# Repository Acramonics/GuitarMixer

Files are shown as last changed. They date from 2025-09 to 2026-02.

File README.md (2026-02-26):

AEGM: Acoustic/Electric Guitar Mixer
====================================

**Andrew Martin (c) 2025 - 2026**

**Still not working properly yet**

**V1.3 has switched to a dual rail power supply to save the effort of
  biasing all the op amp inputs. Awaiting the new boards**

*AEGM* is designed as a simple 2-channel mixer for guitars like the
PRS range that have both acoustic (piezo) and coil pickups. The
guitars have a combined output, but it doesn't work that well since
the piezo output needs a higher impedance than a standard guitar amp
to work well and your options for balancing the volumes are limited.
Also, you cannot use a pedal on the coil output without also putting
it on the piezo output.

The guitar gives you the option of using two separate outputs which is
fine if you have two amps, but this little mixer is designed to allow
you to use the two outputs separately and then send them to a single
amp.

**V1.2 was simulated in KiCad-Spice and appeared to be working
  properly, but when built was overlayed with noise and distorted.**

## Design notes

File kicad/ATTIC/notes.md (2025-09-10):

Things to try to make this work
===============================

1. Try using DC coupling on the 'scope

2. Try a larger PSU voltage

3. Try more PSU smoothing

4. Try the mixer stage alone on music

5. Try the buffer stage alone on music

Filtering
---------

4. Do we have just an HF effect or also ringing (impedance problems)?

5. Add 1K/10nF R-C low pass filter - before or after the opamp

6. Add 22pF cap U2 Pin3 to ground for high frequencies

Decoupling
----------

7. Add 470nF or 1uF cap between R5/R7 and U2 Pin2

8. Or add 100nF before R5 and R7

9. Try 100R and 10uF (+ to output) after opamp

Gain / feedback
---------------

10. Try R11 at 10k or 1k or shorted to reduce gain of inverter

11. Try R10 at 10K or 1k to reduce gain

12. Try R10 at 220k to increase gain

13. Add 4.7pF cap in parallel with R10

Bias
----

14. Remove R9 (9v positive bias)

15. Remove R8 (no positive bias)

16. Remove R8 and short R9 (non-inv input straight to earth)

17. Try R8 and R9 at 10K to increase current

18. Try C8 = 1uF or 47uF

19. Try C8 = 2.2uF and C7 = 22uF

Impedance matching
------------------

20. Try R5/R7 at 1K to reduce output impedance (and noise) from buffers

Major changes
-------------

21. Try separating signal ground from -ve power

22. Try a non-inverting amplifier for the mixer part (see below)

--------------------------------------------------------------------

Square wave testing
-------------------

https://sound-au.com/articles/squarewave.htm

High-frequency boost leads to peak at the start

1K + 10nF low pass filter (~16kHz) might help

Might prefer to use a higher-order 24dB/octave filter tuned to (say)
22kHz.

A descending flat top of a square wave indicates bass attentuation
An ascending flat top of a square wave indicates bass boost

Non-inverting amp
-----------------
https://share.google/images/nToTiObG5TNGJYSms
https://www.allaboutcircuits.com/video-tutorials/basic-amplifier-configurations-non-inverting-amplifier/

```
           | \
Vin -------|+ \
           |   \___________ Vout
           |   /        |
       ----|- /         |
       |   | /          |
       |                |
       +------|R2|------|
       |
       |
      ---
       R1
      ---
       |
       |
      GND

Vout = Gcl (closed-loop gain) = 1 + (R2/R1)
```

Other web pages:
----------------
https://www.reddit.com/r/diypedals/s/R89ESHo1lh
Transistor based mixer: http://www.seekic.com/circuit_diagram/Audio_Circuit/Mixer/
Other mixer circuits: http://www.seekic.com/circuit_diagram/Audio_Circuit/Mixer/
JFET mixer: https://www.diy-electronic-projects.com/p30-FET-Audio-Mixer
Inverting OpAmp mixer: https://es.pinterest.com/pin/714031715956747662/
Hybrid mixer: https://www.electroniq.net/audio/hybrid-2-channel-audio-mixer-circuit.html#google_vignette
Dual rail mixer: https://modwiggler.com/forum/viewtopic.php?t=258014
GGG Mixer: https://generalguitargadgets.com/pdf/ggg_mixer_sc.pdf
Vero Mixer: https://tagboardeffects.blogspot.com/2013/01/2-channel-mixer.html

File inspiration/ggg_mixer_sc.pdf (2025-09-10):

# Mini Mixer

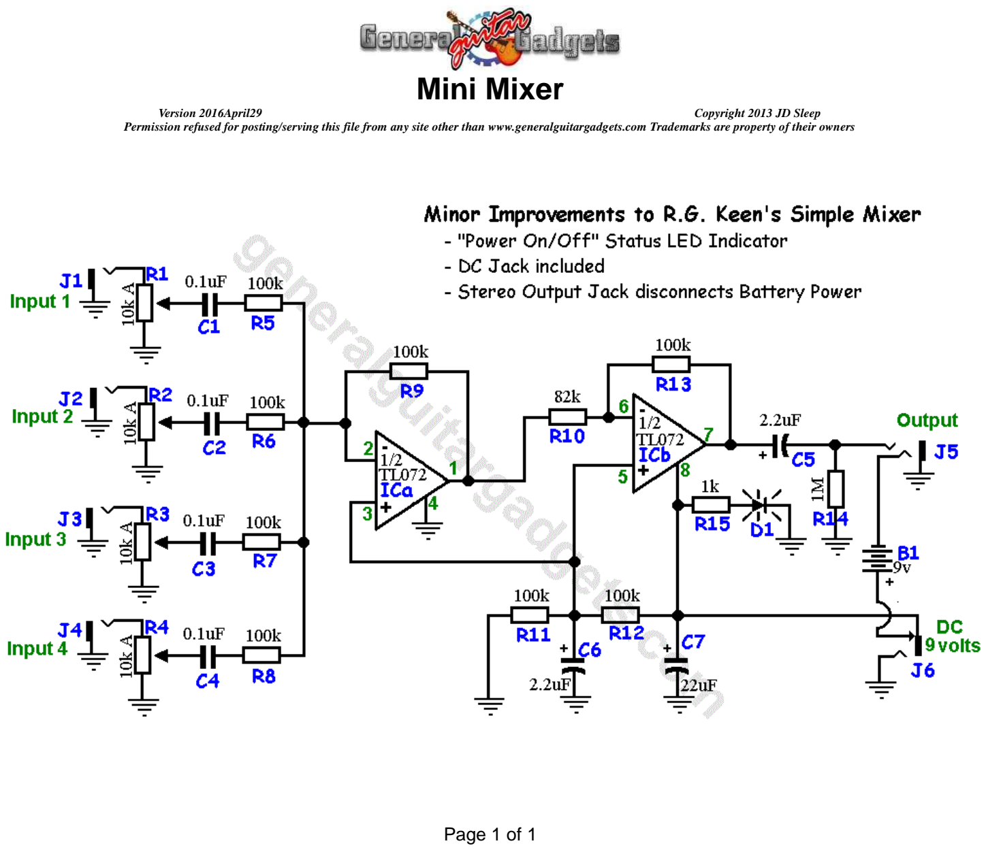
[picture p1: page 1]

Version 2016April29 | Copyright 2013 JD Sleep
Permission refused for posting/serving this file from any site other than www.generalguitargadgets.com Trademarks are property of their owners

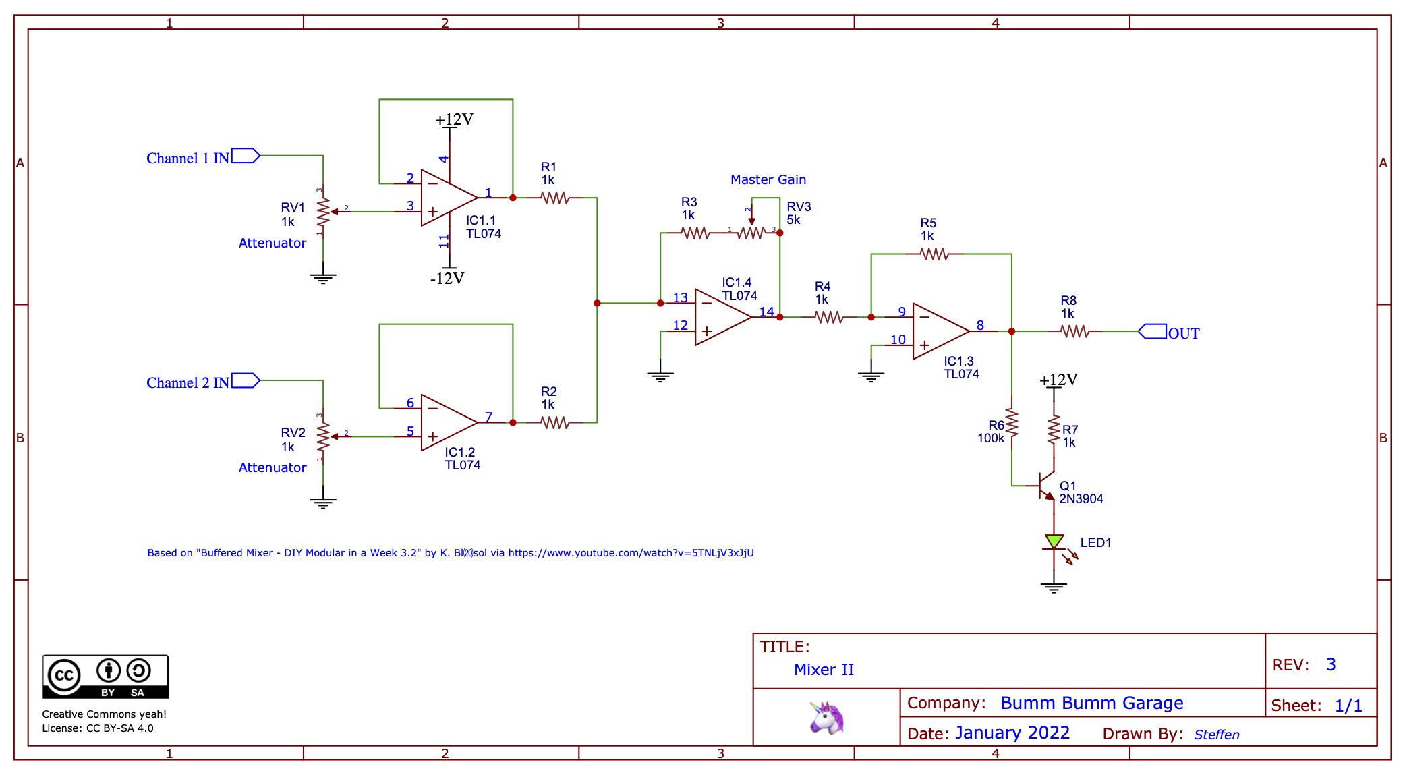
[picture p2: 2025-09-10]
inspiration/Bumm-Bumm-Garage-Mixer-II-Rev3-Schematic.png

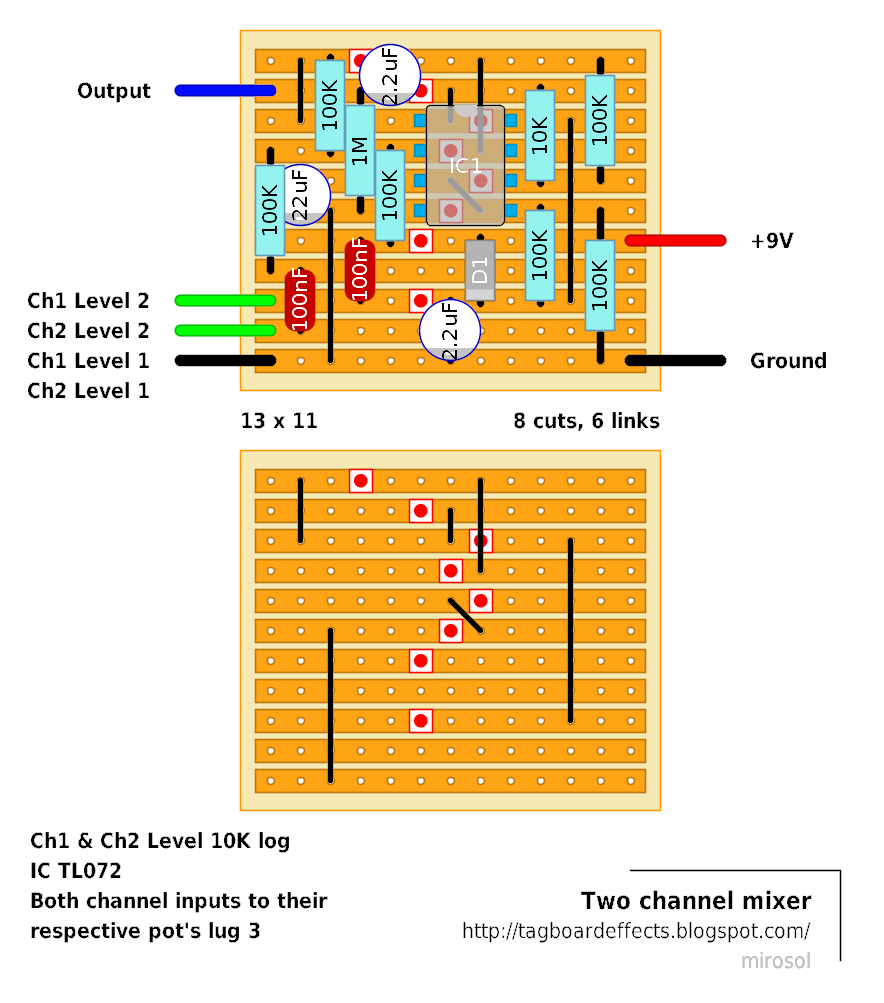
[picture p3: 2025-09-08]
inspiration/2chan-mixer-rev1-light.png

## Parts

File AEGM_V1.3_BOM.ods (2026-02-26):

Reference | Qty | Value | Footprint
C1,C2 | 2 | 10pF | Capacitor_THT:C_Disc_D4.3mm_W1.9mm_P5.00mm
C3 | 1 | 2.2uF | Capacitor_THT:CP_Radial_D5.0mm_P2.00mm
C4,C8,C9 | 3 | 100nF | Capacitor_THT:C_Rect_L7.0mm_W3.5mm_P5.00mm
C5,C6 | 2 | 22uF | Capacitor_THT:CP_Radial_D5.0mm_P2.00mm
C7 | 1 | 10uF | Capacitor_THT:CP_Radial_D5.0mm_P2.00mm
C101 | 1 | 1pF | Capacitor_THT:C_Disc_D4.3mm_W1.9mm_P5.00mm
C102 | 1 | 4.7nF | Capacitor_THT:C_Rect_L7.2mm_W2.5mm_P5.00mm_FKS2_FKP2_MKS2_MKP2
C103 | 1 | 330nF | Capacitor_THT:C_Rect_L7.2mm_W2.5mm_P5.00mm_FKS2_FKP2_MKS2_MKP2
C105,C205 | 2 | 1uF | Capacitor_THT:C_Rect_L7.2mm_W4.5mm_P5.00mm_FKS2_FKP2_MKS2_MKP2
C203 | 1 | 100nF | Capacitor_THT:C_Rect_L7.2mm_W2.5mm_P5.00mm_FKS2_FKP2_MKS2_MKP2
D1 | 1 | 1N5817 | Diode_THT:D_DO-35_SOD27_P7.62mm_Horizontal
J1,J2,J3,J6 | 4 | Conn_01x03_Pin | Connector_Molex:Molex_KK-254_AE-6410-03A_1x03_P2.54mm_Vertical
J4,J5 | 2 | Conn_01x02_Pin | Connector_Molex:Molex_KK-254_AE-6410-02A_1x02_P2.54mm_Vertical
Q1 | 1 | 2N5457 | Package_TO_SOT_THT:TO-92_HandSolder
R1,R2,R3,R103 | 4 | 10K | Resistor_THT:R_Axial_DIN0207_L6.3mm_D2.5mm_P10.16mm_Horizontal
R4,R201 | 2 | 1M | Resistor_THT:R_Axial_DIN0207_L6.3mm_D2.5mm_P10.16mm_Horizontal
R5 | 1 | 680R | Resistor_THT:R_Axial_DIN0207_L6.3mm_D2.5mm_P2.54mm_Vertical
R6 | 1 | 220R | Resistor_THT:R_Axial_DIN0207_L6.3mm_D2.5mm_P2.54mm_Vertical
R102 | 1 | 220K | Resistor_THT:R_Axial_DIN0207_L6.3mm_D2.5mm_P10.16mm_Horizontal
R108,R208 | 2 | 4K7 | Resistor_THT:R_Axial_DIN0207_L6.3mm_D2.5mm_P2.54mm_Vertical
R1011,R1012 | 2 | 4M7 | Resistor_THT:R_Axial_DIN0207_L6.3mm_D2.5mm_P10.16mm_Horizontal
RV1 | 1 | 100KB | 100K Linear Pot
RV101,RV201 | 2 | A100K | 100K Audio (Log) Pot
SW1 | 1 | SW_SPST | ACRM:SPDT_SlideSwitch
U1,U2 | 2 | TL072 | Package_DIP:DIP-8_W7.62mm
U3 | 1 | LM317L | Package_TO_SOT_THT:TO-92_HandSolder
U4 | 1 | LMC7660 | Package_DIP:DIP-8_W7.62mm

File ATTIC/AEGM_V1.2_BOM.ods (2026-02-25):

Reference | Qty | Value | Footprint
C1,C2 | 2 | 10pF | Capacitor_THT:C_Disc_D4.3mm_W1.9mm_P5.00mm
C3 | 1 | 2.2uF | Capacitor_THT:CP_Radial_D5.0mm_P2.00mm
C4 | 1 | 4.7uF | Capacitor_THT:CP_Radial_D5.0mm_P2.00mm
C5 | 1 | 22uF | Capacitor_THT:CP_Radial_D5.0mm_P2.00mm
C101 | 1 | 1pF | Capacitor_THT:C_Disc_D4.3mm_W1.9mm_P5.00mm
C102 | 1 | 4.7nF | Capacitor_THT:C_Rect_L7.2mm_W2.5mm_P5.00mm_FKS2_FKP2_MKS2_MKP2
C103,C104,C203,C204 | 4 | 100nF | Capacitor_THT:C_Rect_L7.2mm_W2.5mm_P5.00mm_FKS2_FKP2_MKS2_MKP2
C105,C205 | 2 | 1uF | Capacitor_THT:C_Rect_L7.2mm_W4.5mm_P5.00mm_FKS2_FKP2_MKS2_MKP2
C202 | 1 | 1nF | Capacitor_THT:C_Rect_L7.2mm_W2.5mm_P5.00mm_FKS2_FKP2_MKS2_MKP2
D1 | 1 | 1N5817 | Diode_THT:D_DO-41_SOD81_P10.16mm_Horizontal
J1,J2,J3,J6 | 4 | Conn_01x03_Pin | Connector_Molex:Molex_KK-254_AE-6410-03A_1x03_P2.54mm_Vertical
J4,J5 | 2 | Conn_01x02_Pin | Connector_Molex:Molex_KK-254_AE-6410-02A_1x02_P2.54mm_Vertical
Q1 | 1 | 2N5457 | Package_TO_SOT_THT:TO-92_HandSolder
R1,R2,R3,R103,R108,R208 | 6 | 10K | Resistor_THT:R_Axial_DIN0207_L6.3mm_D2.5mm_P10.16mm_Horizontal
R4,R201 | 2 | 1M | Resistor_THT:R_Axial_DIN0207_L6.3mm_D2.5mm_P10.16mm_Horizontal
R5,R6,R104,R105,R204,R205 | 6 | 100K | Resistor_THT:R_Axial_DIN0207_L6.3mm_D2.5mm_P10.16mm_Horizontal
R102 | 1 | 220K | Resistor_THT:R_Axial_DIN0207_L6.3mm_D2.5mm_P10.16mm_Horizontal
R106,R107,R206,R207 | 4 | 1K | Resistor_THT:R_Axial_DIN0207_L6.3mm_D2.5mm_P10.16mm_Horizontal
R1011,R1012 | 2 | 4M7 | Resistor_THT:R_Axial_DIN0207_L6.3mm_D2.5mm_P10.16mm_Horizontal
RV1 | 1 | B100K
RV101,RV201 | 2 | A100K
SW1 | 1 | SW_SPST | ACRM:SPDT_SlideSwitch
U1,U2 | 2 | TL072 | Package_DIP:DIP-8_W7.62mm

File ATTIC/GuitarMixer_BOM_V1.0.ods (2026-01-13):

Reference | Qty | Value | Footprint
C1 | 1 | 1pF | Capacitor_THT:C_Disc_D4.3mm_W1.9mm_P5.00mm
C2 | 1 | 33nF | Capacitor_THT:C_Rect_L7.2mm_W2.5mm_P5.00mm_FKS2_FKP2_MKS2_MKP2
C3,C4,C11 | 3 | 100nF | Capacitor_THT:C_Rect_L7.2mm_W2.5mm_P5.00mm_FKS2_FKP2_MKS2_MKP2
C5,C6 | 2 | 1uF | Capacitor_THT:C_Rect_L7.2mm_W4.5mm_P5.00mm_FKS2_FKP2_MKS2_MKP2
C7 | 1 | 4.7uF | Capacitor_THT:CP_Radial_D5.0mm_P2.00mm
C8 | 1 | 22uF | Capacitor_THT:CP_Radial_D5.0mm_P2.00mm
C9 | 1 | 2.2uF | Capacitor_THT:CP_Radial_D5.0mm_P2.00mm
C10 | 1 | 10pF | Capacitor_THT:C_Disc_D4.3mm_W1.9mm_P5.00mm
D1 | 1 | 1N5817 | Diode_THT:D_DO-41_SOD81_P10.16mm_Horizontal
J1,J2,J3,J6 | 4 | Conn_01x03_Pin | Connector_Molex:Molex_KK-254_AE-6410-03A_1x03_P2.54mm_Vertical
J4,J5 | 2 | Conn_01x02_Pin | Connector_Molex:Molex_KK-254_AE-6410-02A_1x02_P2.54mm_Vertical
Q1 | 1 | 2N5457 | Package_TO_SOT_THT:TO-92_HandSolder
R1,R2 | 2 | 4M7 | Resistor_THT:R_Axial_DIN0207_L6.3mm_D2.5mm_P10.16mm_Horizontal
R3 | 1 | 220K | Resistor_THT:R_Axial_DIN0207_L6.3mm_D2.5mm_P10.16mm_Horizontal
R4,R5,R7,R10,R12,R14 | 6 | 10K | Resistor_THT:R_Axial_DIN0207_L6.3mm_D2.5mm_P10.16mm_Horizontal
R6,R13 | 2 | 1M | Resistor_THT:R_Axial_DIN0207_L6.3mm_D2.5mm_P10.16mm_Horizontal
R8,R9,R11 | 3 | 100K | Resistor_THT:R_Axial_DIN0207_L6.3mm_D2.5mm_P10.16mm_Horizontal
RV1,RV2 | 2 | A100K
RV3 | 1 | 100KB
SW1 | 1 | SW_SPST | ACRM:SPDT_SlideSwitch
U1,U2 | 2 | TL072 | Package_DIP:DIP-8_W7.62mm

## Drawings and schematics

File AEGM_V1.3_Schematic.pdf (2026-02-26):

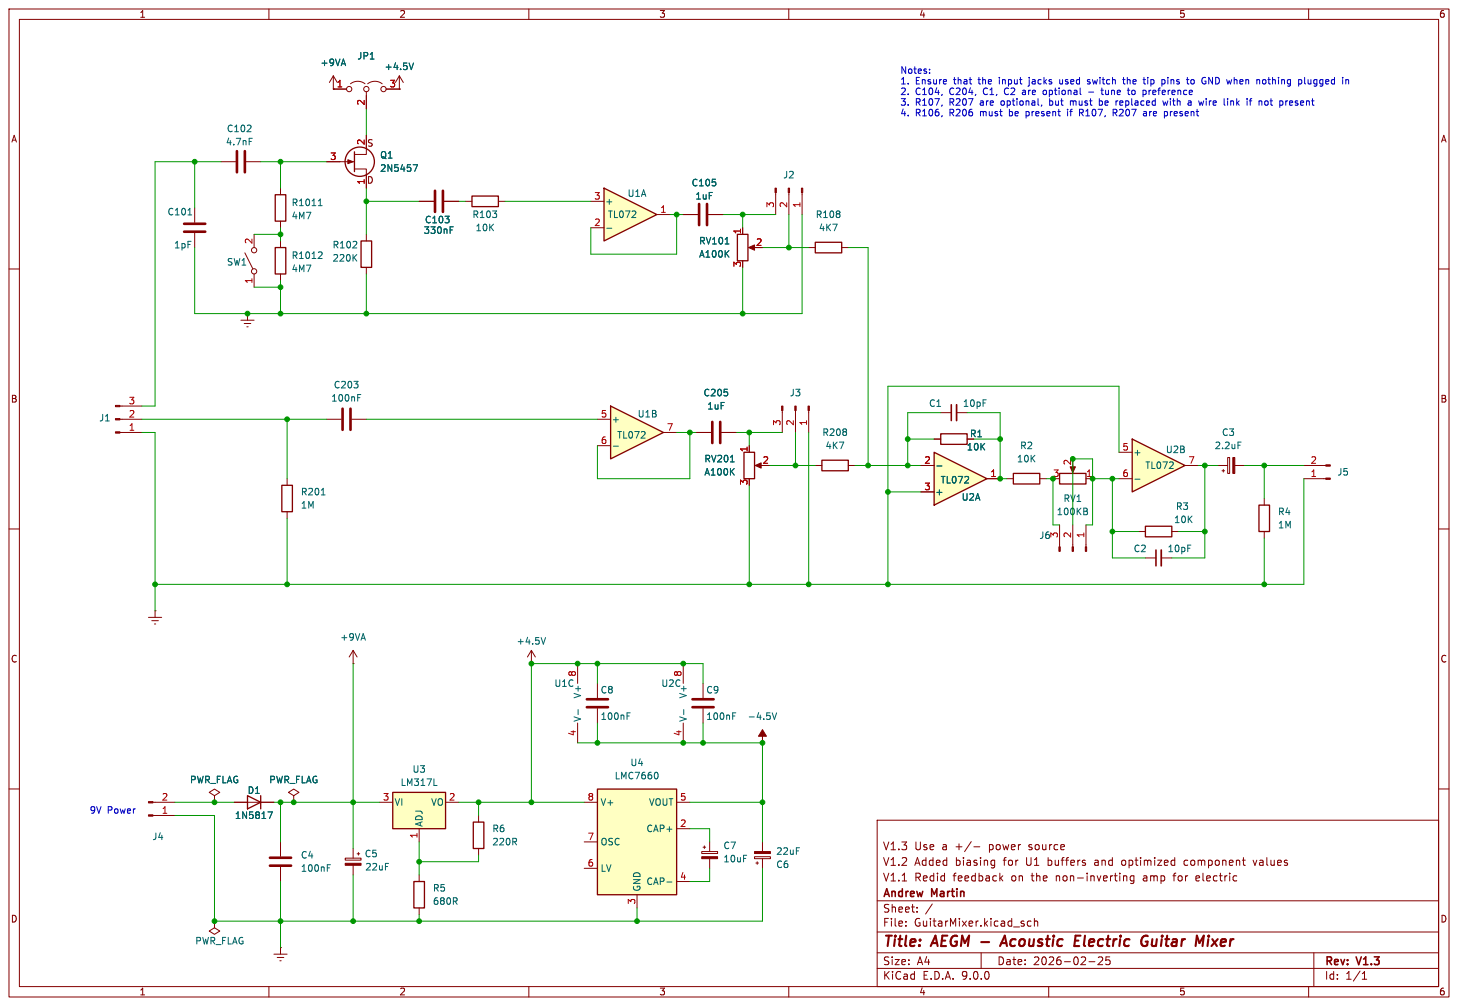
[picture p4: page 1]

Notes: 1. Ensure that the input jacks used switch the tip pins to GND when nothing plugged in

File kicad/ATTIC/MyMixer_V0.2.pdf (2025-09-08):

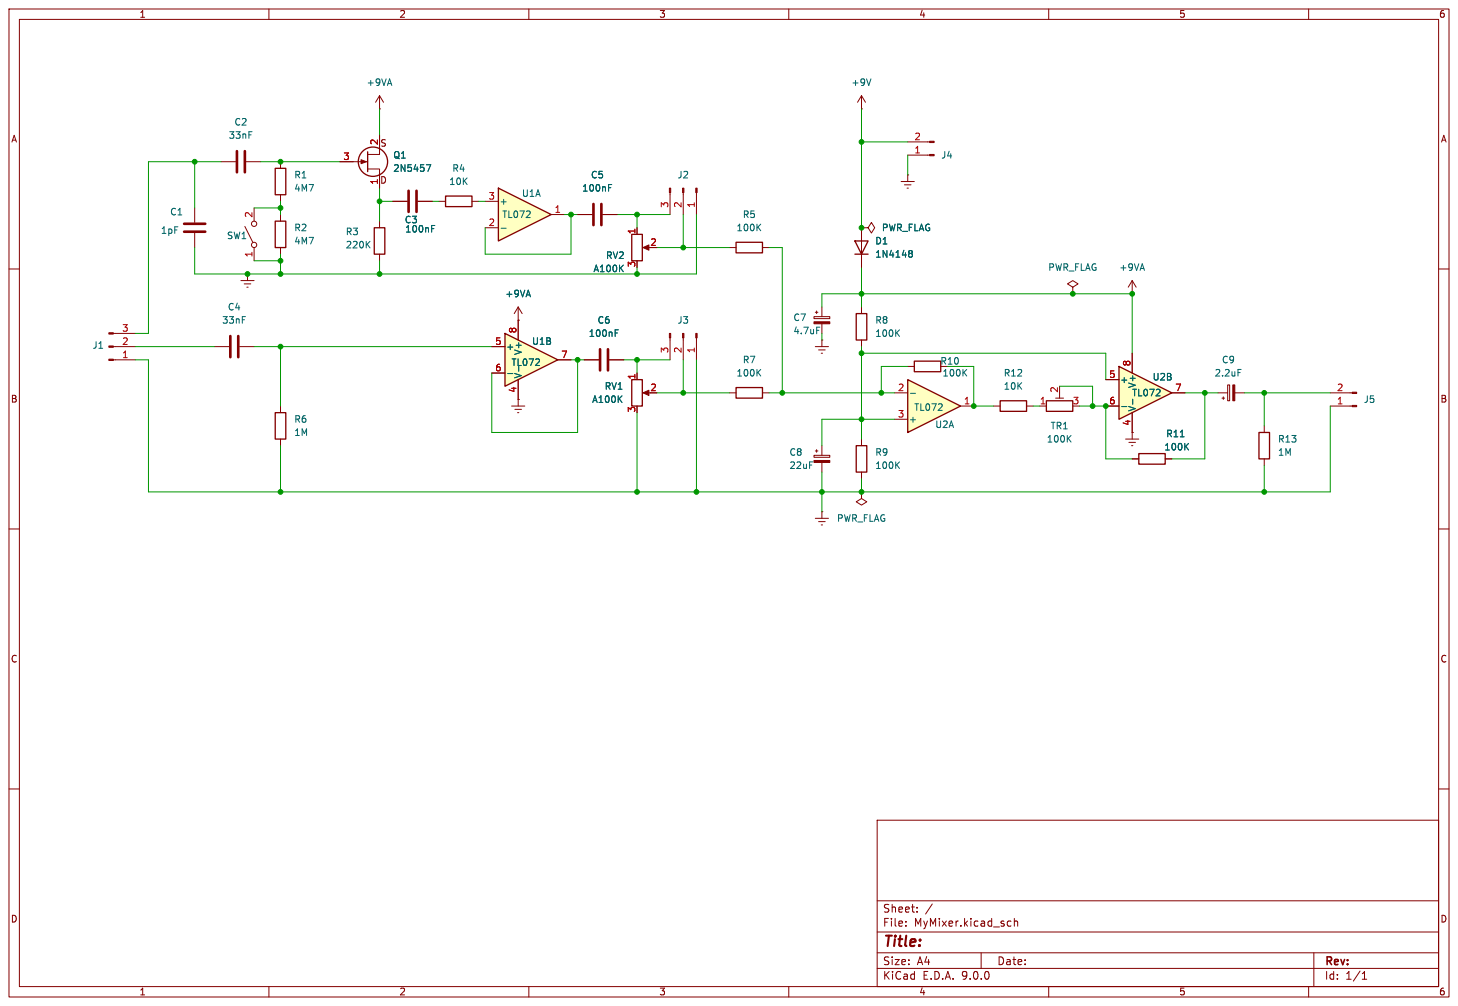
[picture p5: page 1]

Id: 1/1 Title: File: MyMixer.kicad_sch Sheet: / R9

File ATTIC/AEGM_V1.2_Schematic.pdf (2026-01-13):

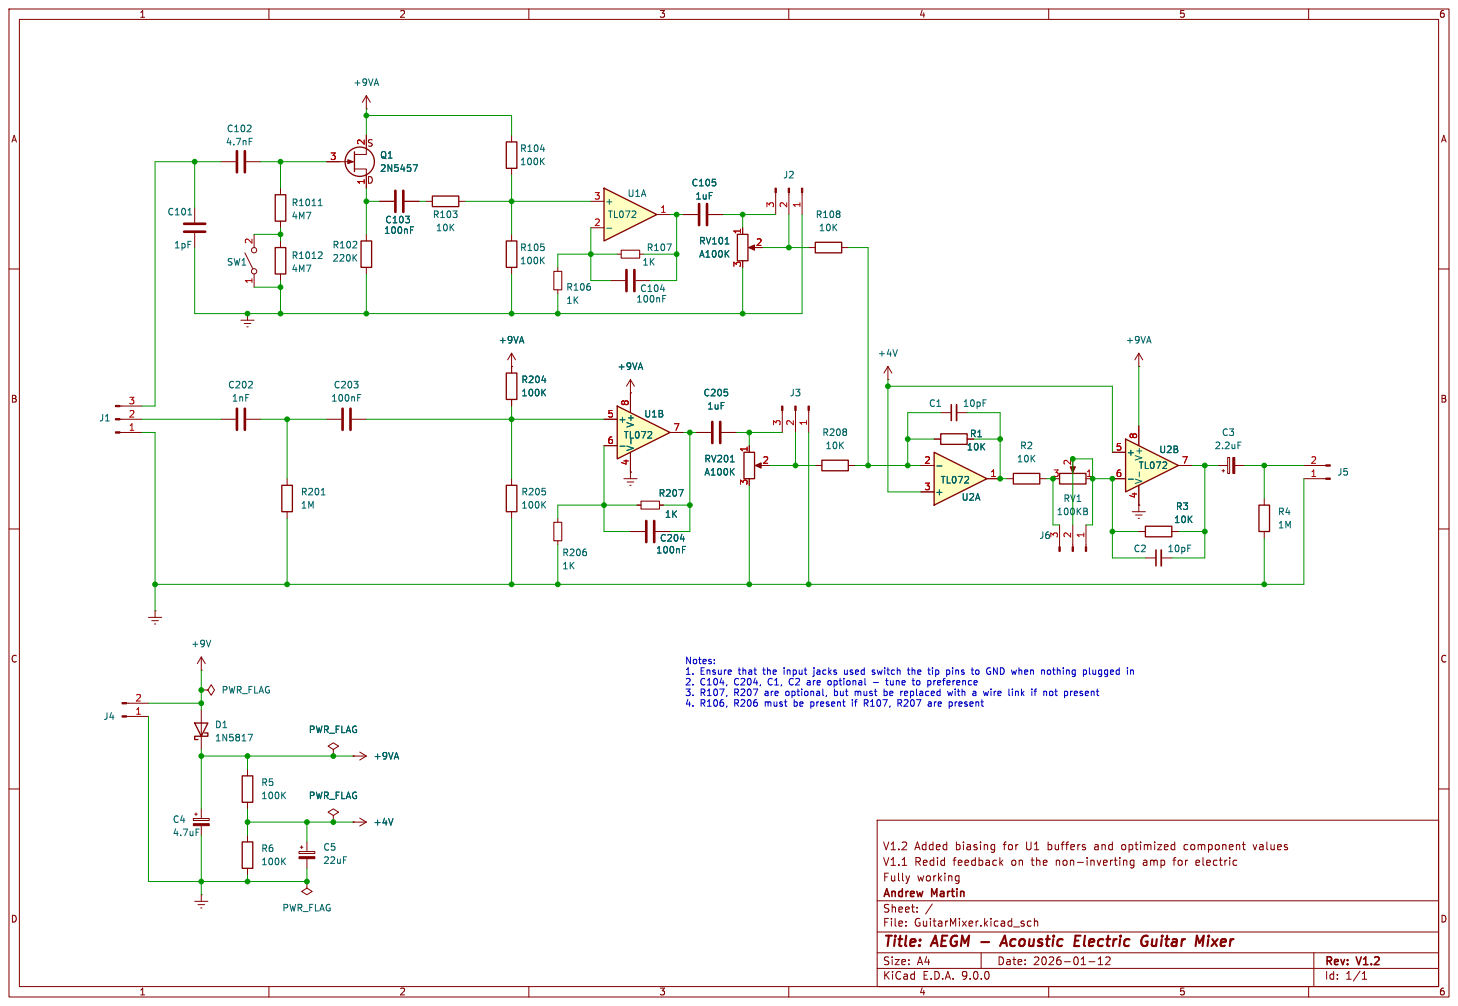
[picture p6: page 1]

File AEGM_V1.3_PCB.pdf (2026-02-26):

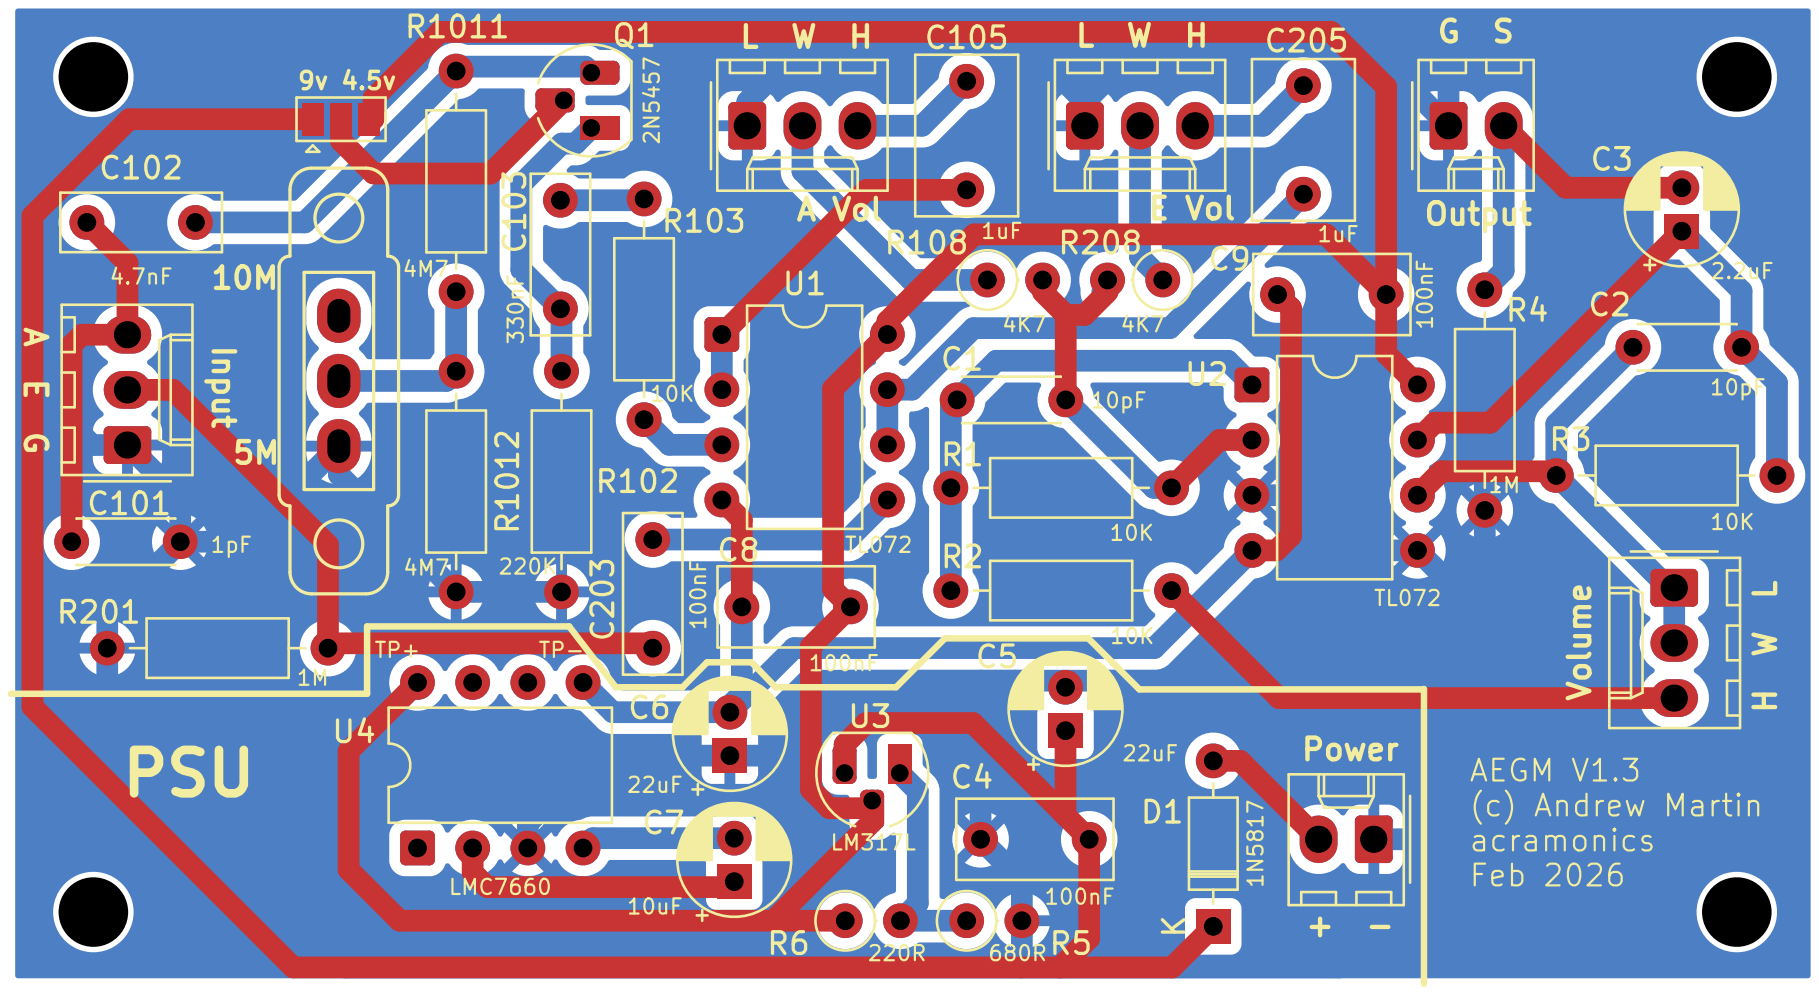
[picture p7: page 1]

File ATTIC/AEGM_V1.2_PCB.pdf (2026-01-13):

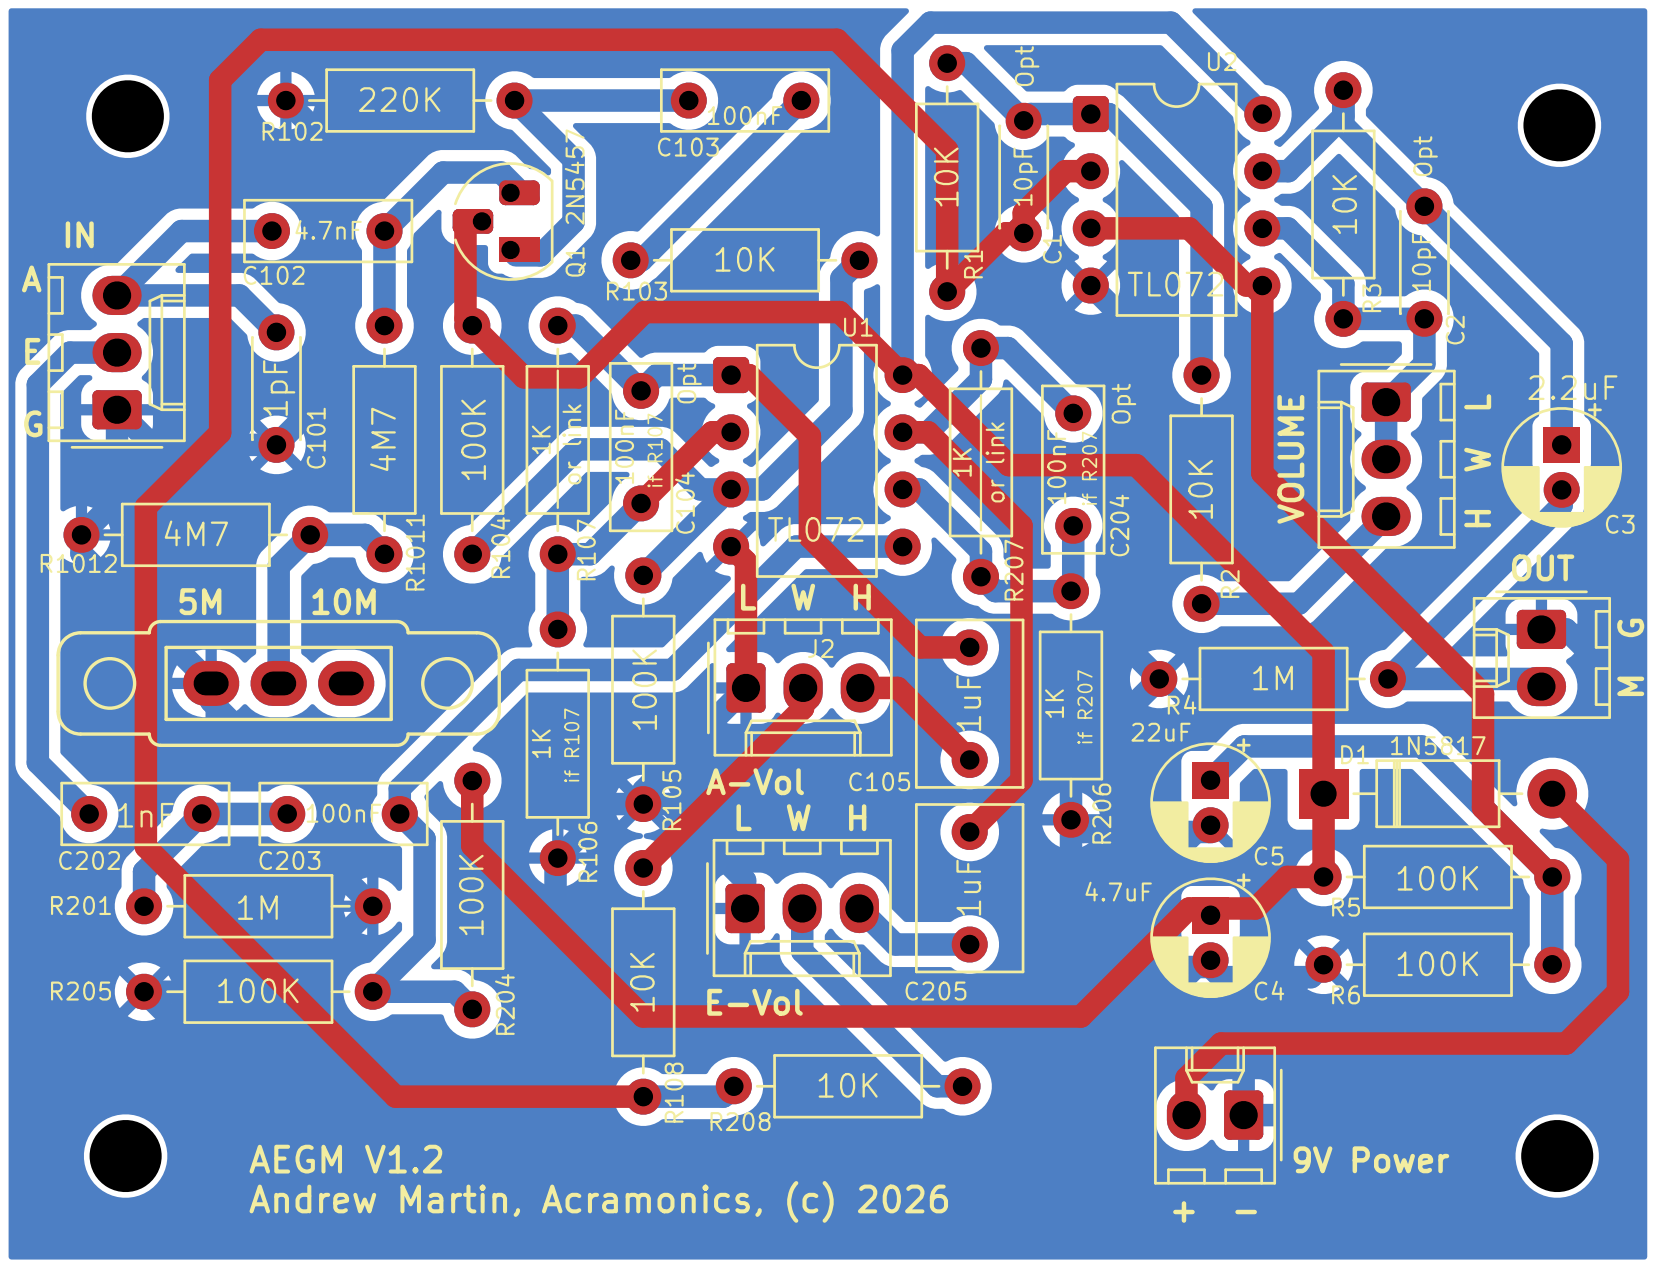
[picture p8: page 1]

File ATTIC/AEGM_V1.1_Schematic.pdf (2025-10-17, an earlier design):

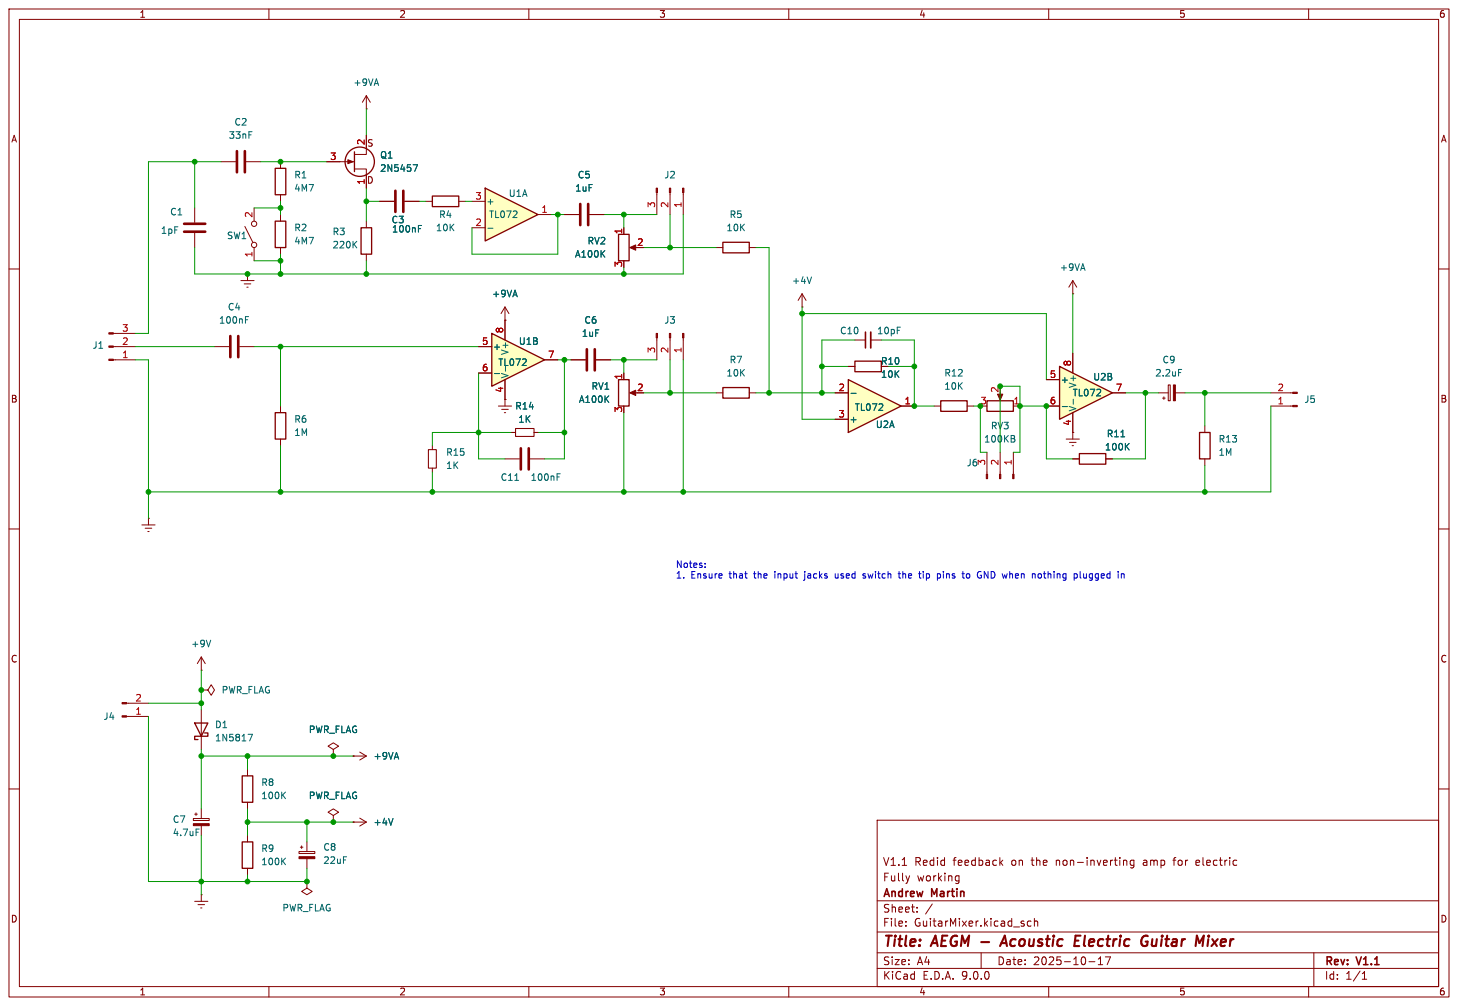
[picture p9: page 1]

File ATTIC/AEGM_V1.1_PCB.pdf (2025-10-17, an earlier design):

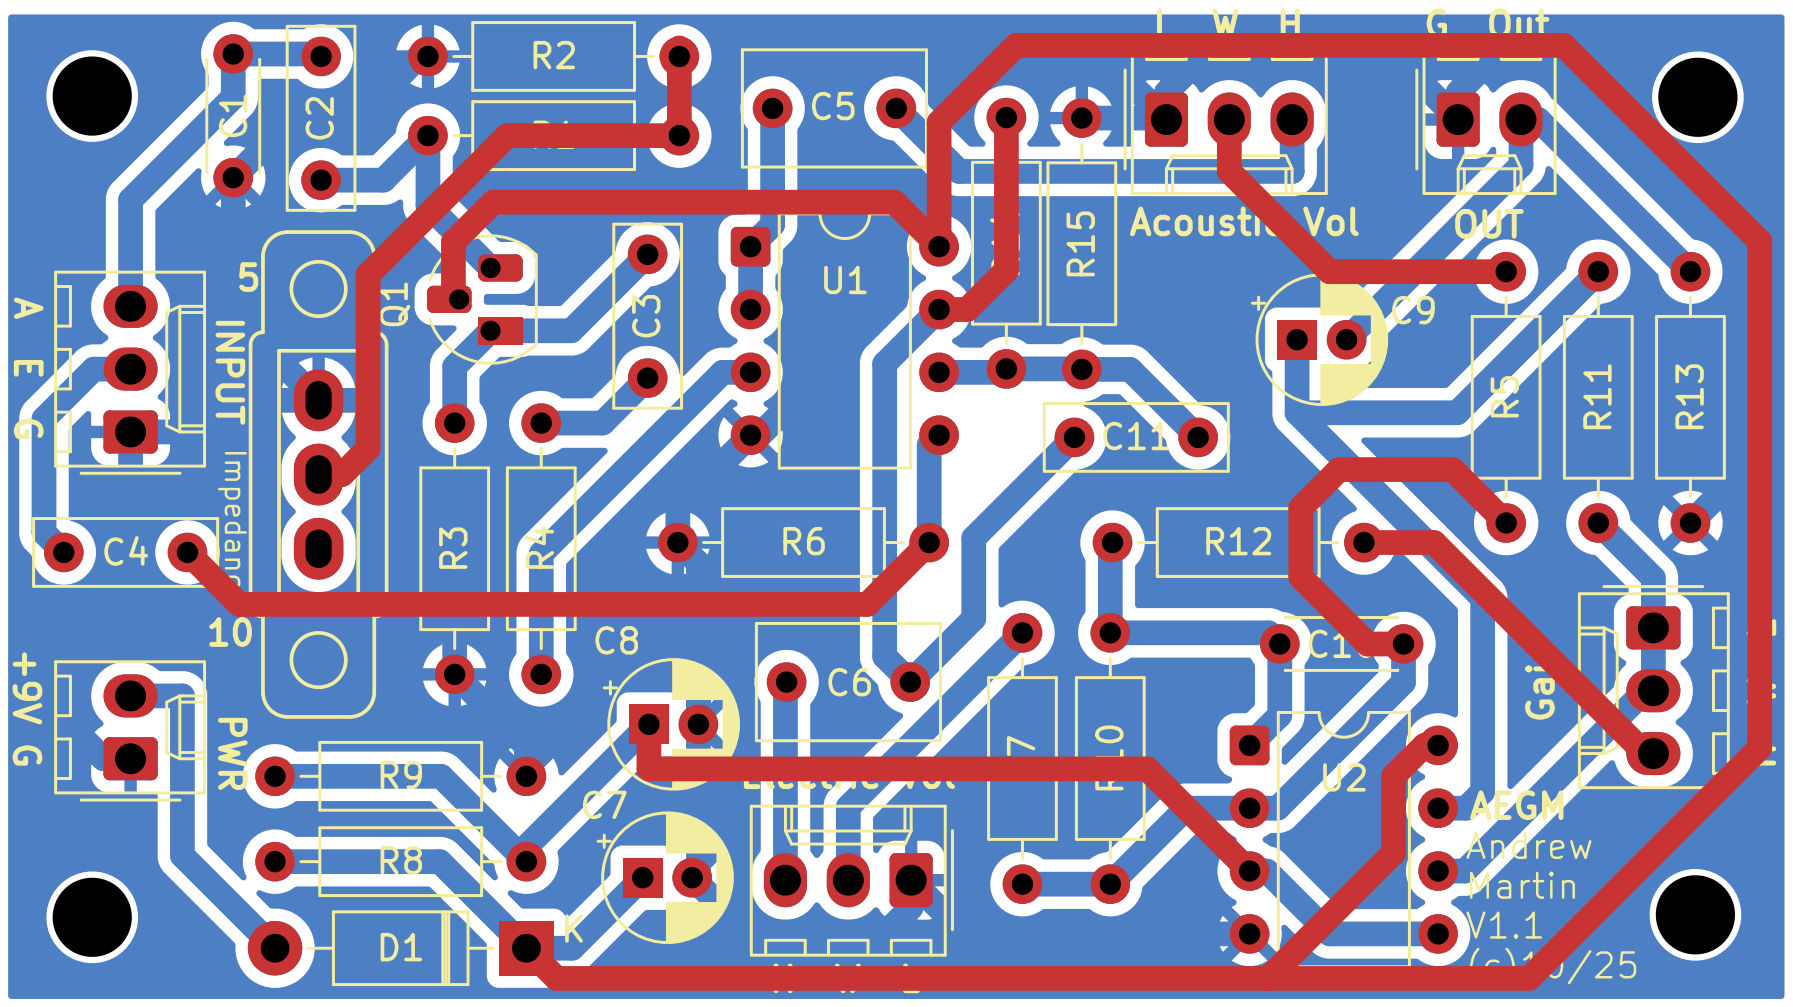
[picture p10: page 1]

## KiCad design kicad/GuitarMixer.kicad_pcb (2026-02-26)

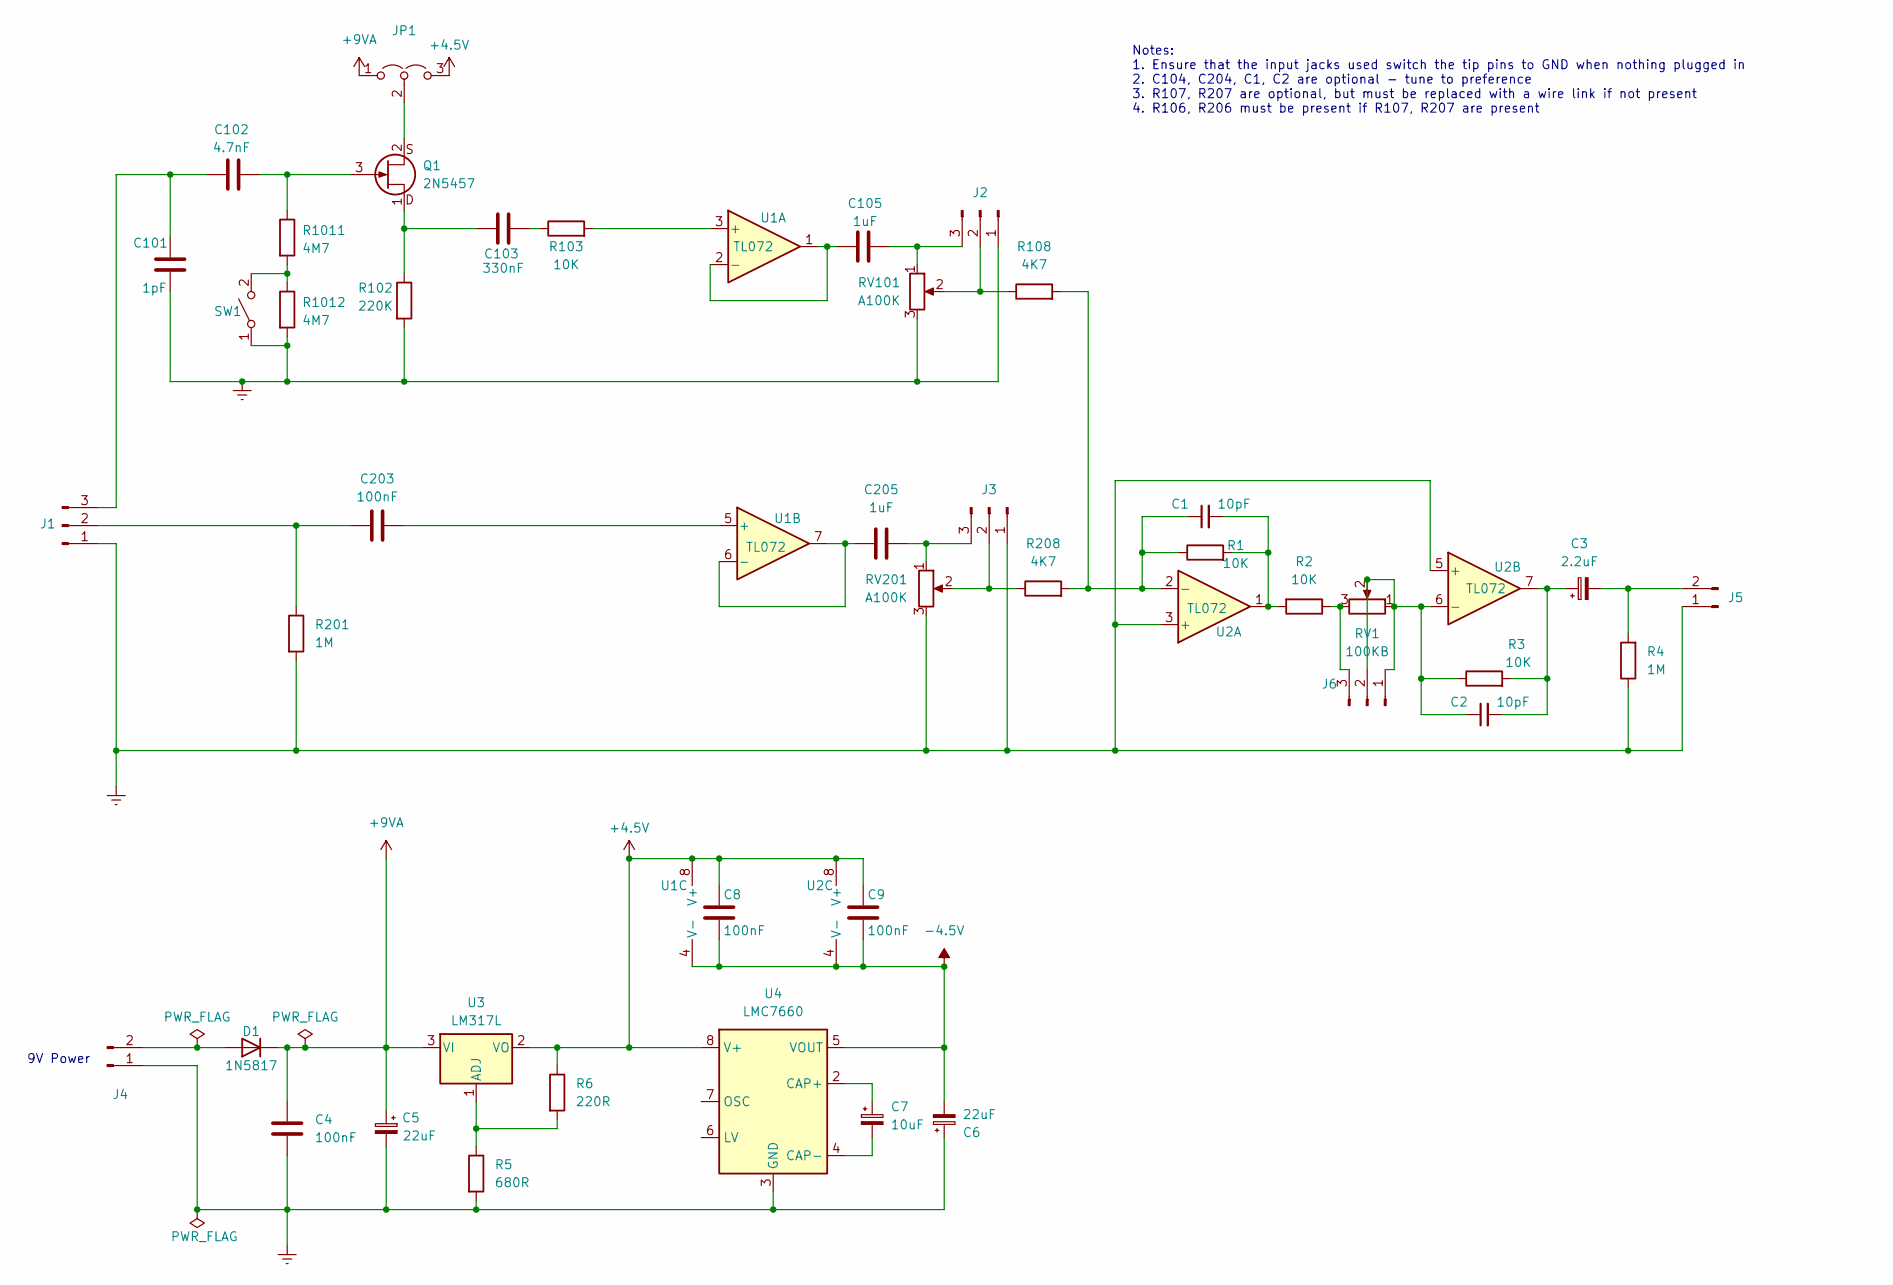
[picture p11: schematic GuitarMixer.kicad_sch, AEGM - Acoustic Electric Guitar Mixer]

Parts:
C1, C2: 10pF; C_Disc_D4.3mm_W1.9mm_P5.00mm
C3: 2.2uF; CP_Radial_D5.0mm_P2.00mm
C4, C8, C9: 100nF; C_Rect_L7.0mm_W3.5mm_P5.00mm
C5, C6: 22uF; CP_Radial_D5.0mm_P2.00mm
C7: 10uF; CP_Radial_D5.0mm_P2.00mm
C101: 1pF; C_Disc_D4.3mm_W1.9mm_P5.00mm
C102: 4.7nF; C_Rect_L7.2mm_W2.5mm_P5.00mm_FKS2_FKP2_MKS2_MKP2
C103: 330nF; C_Rect_L7.2mm_W2.5mm_P5.00mm_FKS2_FKP2_MKS2_MKP2
C105, C205: 1uF; C_Rect_L7.2mm_W4.5mm_P5.00mm_FKS2_FKP2_MKS2_MKP2
C203: 100nF; C_Rect_L7.2mm_W2.5mm_P5.00mm_FKS2_FKP2_MKS2_MKP2
D1: 1N5817; D_DO-35_SOD27_P7.62mm_Horizontal
J1, J2, J3, J6: Conn_01x03_Pin; Molex_KK-254_AE-6410-03A_1x03_P2.54mm_Vertical
J4, J5: Conn_01x02_Pin; Molex_KK-254_AE-6410-02A_1x02_P2.54mm_Vertical
JP1: Jumper_3_Open; SolderJumper-3_P1.3mm_Open_Pad1.0x1.5mm
Q1: 2N5457; TO-92_HandSolder
R1, R2, R3, R103: 10K; R_Axial_DIN0207_L6.3mm_D2.5mm_P10.16mm_Horizontal
R4, R201: 1M; R_Axial_DIN0207_L6.3mm_D2.5mm_P10.16mm_Horizontal
R5: 680R; R_Axial_DIN0207_L6.3mm_D2.5mm_P2.54mm_Vertical
R6: 220R; R_Axial_DIN0207_L6.3mm_D2.5mm_P2.54mm_Vertical
R102: 220K; R_Axial_DIN0207_L6.3mm_D2.5mm_P10.16mm_Horizontal
R108, R208: 4K7; R_Axial_DIN0207_L6.3mm_D2.5mm_P2.54mm_Vertical
R1011, R1012: 4M7; R_Axial_DIN0207_L6.3mm_D2.5mm_P10.16mm_Horizontal
RV1: 100KB
RV101, RV201: A100K
SW1: SW_SPST; SPDT_SlideSwitch
U1, U2: TL072; DIP-8_W7.62mm
U3: LM317L; TO-92_HandSolder
U4: LMC7660; DIP-8_W7.62mm

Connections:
+4.5V: C8.1, C9.1, JP1.3 (B), R6.1, U1.8 (V+), U2.8 (V+), U3.2 (VO), U4.8 (V+)
+9VA: C4.1, C5.1, D1.1 (K), JP1.1 (A), U3.3 (VI)
-4.5V: C6.2, C8.2, C9.2, U1.4 (V-), U2.4 (V-), U4.5 (VOUT)
Earth: C4.2, C5.2, C6.1, C101.2, J1.1, J2.1, J3.1, J4.1, J5.1, R4.1, R5.2, R102.2, R201.2, R1012.2, RV101.3, RV201.3, SW1.1 (A), U2.3 (+), U2.5 (+), U4.3 (GND)
unnamed: C1.2, R1.2, R2.2, U2.1
unnamed: C2.2, C3.1, R3.2, U2.7
unnamed: C103.2, R103.1
unnamed: D1.2 (A), J4.2
unnamed: C203.1, J1.2, R201.1
unnamed: C101.1, C102.1, J1.3
unnamed: J2.2, R108.1, RV101.2
unnamed: C105.2, J2.3, RV101.1
unnamed: J3.2, R208.1, RV201.2
unnamed: C205.2, J3.3, RV201.1
unnamed: C3.2, J5.2, R4.2
unnamed: C2.1, J6.1, J6.2, R3.1, RV1.1, RV1.2, U2.6 (-)
unnamed: J6.3, R2.1, RV1.3
unnamed: JP1.2 (C), Q1.2 (D)
unnamed: C102.2, Q1.3 (G), R1011.1
unnamed: C103.1, Q1.1 (S), R102.1
unnamed: R1011.2, R1012.1, SW1.2 (B)
unnamed: R103.2, U1.3 (+)
unnamed: C105.1, U1.1, U1.2 (-)
unnamed: C203.2, U1.5 (+)
unnamed: C205.1, U1.6 (-), U1.7
unnamed: C1.1, R1.1, R108.2, R208.2, U2.2 (-)
unnamed: R5.1, R6.2, U3.1 (ADJ)
unnamed: C7.1, U4.2 (CAP+)
unnamed: C7.2, U4.4 (CAP-)

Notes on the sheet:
9V Power
Notes: 1. Ensure that the input jacks used switch the tip pins to GND when nothing plugged in 2. C104, C204, C1, C2 are optional - tune to preference 3. R107, R207 are optional, but must be replaced with a wire link if not present 4. R106, R206 must be present if R107, R207 are present

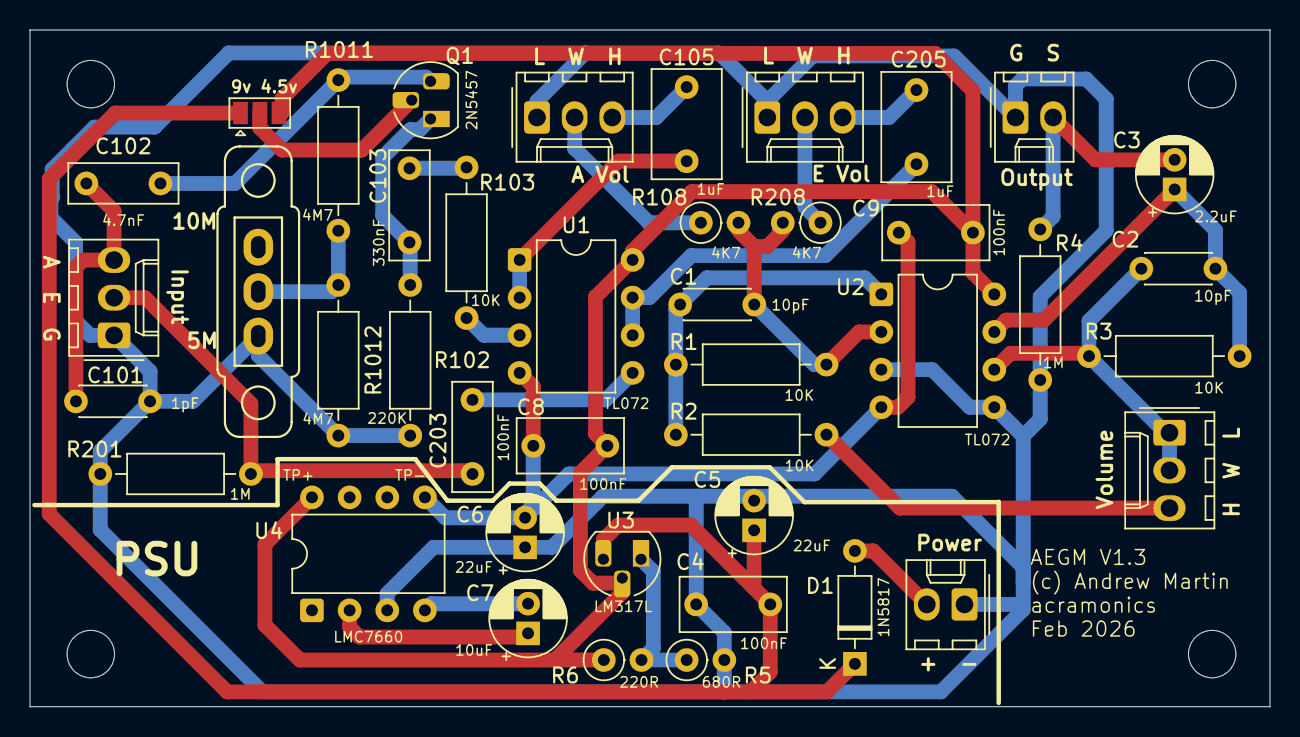
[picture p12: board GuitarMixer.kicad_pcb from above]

Board: 2 copper layers, 83.7 x 45.6 mm, 42 parts (0 on the bottom side), 29 nets.

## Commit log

2025-09-08 Initial Commit V0.2
    [GuitarMixer-B_Cu.gbr, GuitarMixer-B_Mask.gbr, GuitarMixer-B_Paste.gbr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]
2025-09-08 Removed redundant files
    [MyMixer-B_Cu.gbr, MyMixer-B_Mask.gbr, MyMixer-B_Paste.gbr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]
2025-09-08 Added README.md and inspiration directory
    [GuitarMixer-B_Cu.gbr, GuitarMixer-B_Mask.gbr, GuitarMixer-B_Paste.gbr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]
2025-09-08 Fixed slide switch and changed trimmer to pot connection
    [GuitarMixer.kicad_pcb, GuitarMixer.kicad_sch]
2025-09-08 Updated gerber files
    [GuitarMixer-B_Cu.gbr, GuitarMixer-B_Mask.gbr, GuitarMixer-B_Paste.gbr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]
2025-10-08 Added PCB PDF
2025-10-17 Redid the feedback on the non-inverting amplifier for electric guitar
    [GuitarMixer-B_Cu.gbr, GuitarMixer-B_Mask.gbr, GuitarMixer-B_Paste.gbr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]
2026-01-12 Added simulation and updated schematic to V1.2 based on simulation
    [AEGM_LT.kicad_sch, AEGM_LT_Acoustic.kicad_sch, AEGM_LT_Elect.kicad_sch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]
2026-01-13 Board created
    [GuitarMixer.kicad_pcb]
2026-01-13 Fixed swapped labels
    [GuitarMixer-B_Cu.gbr, GuitarMixer-B_Mask.gbr, GuitarMixer-B_Paste.gbr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]
2026-01-13 Added PDF files and BOM
    [AEGM_V1.2_BOM.ods, GuitarMixer_BOM_V1.0.ods]
2026-02-25 Updated BOM
    [AEGM_V1.2_BOM.ods]
2026-02-26 New version with split rail power supply
    [GuitarMixer.kicad_pcb, GuitarMixer.kicad_sch]
2026-02-26 Moved the voltage setting resistors and created gerber and distribution files
    [AEGM_V1.2_BOM.ods, AEGM_V1.3_BOM.ods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]
